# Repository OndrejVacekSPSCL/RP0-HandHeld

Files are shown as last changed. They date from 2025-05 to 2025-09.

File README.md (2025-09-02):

# RP0-HandHeld
>*This project was made for HackClub Highway*

Raspberry Pi Zero 2 gaming handheld, that runs Retro Pie...

I always wanted gaming console that has retro games in it so I made this!

RP0-HandHeld 1

RP0-HandHeld 2

## Repository Layout

The repo is structured as follows:
- PCB-related KiCad files in the `PCB/`
- KiCAD case design in `CAD/`
- Software related stuff is located in `Software/`
- For a rough BOM, see `BOM.csv`
- For my development log, see `JOURNAL.md`
- HackClub Readme is located in `README-original.md`
  
> [!CAUTION]
> The physical version of the console is not finished yet! The tutorial will be made after the completation.

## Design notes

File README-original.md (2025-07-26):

# RP0-HandHeld
Raspberry Pi Zero 2 gaming handheld, that runs Retro Pie...

I always wanted gaming console that has retro games in it so I made this!

RP0-HandHeld 1

RP0-HandHeld 2

It consists of few key parts:
- [Screen](https://github.com/OndrejVacekSPSCL/RP0-HandHeld/edit/main/README.md#screen)
- [Audio](https://github.com/OndrejVacekSPSCL/RP0-HandHeld/edit/main/README.md#audio)
- [Battery and charging](https://github.com/OndrejVacekSPSCL/RP0-HandHeld/edit/main/README.md#battery-and-charging)
- [Inputs](https://github.com/OndrejVacekSPSCL/RP0-HandHeld/edit/main/README.md#inputs)
- [PCB](https://github.com/OndrejVacekSPSCL/RP0-HandHeld/edit/main/README.md#pcb)
- [Case]()
- [Software]()

You can read about how I designed it in [JOURNAL.md](https://github.com/OndrejVacekSPSCL/RP0-HandHeld/blob/main/JOURNAL.md).

## Screen
I found this [screen](https://tinyurl.com/3287bkxc) online. It has the perfect size for my project.



## Audio
Audio is made with help of this [tutorial](https://youtu.be/3pXB90IDNoY?si=AYgq76n8aVKT-kv3).

Parts list:
- 2x [270 Ohm resistors](https://tinyurl.com/ycs5rh84)
- 2x [150 Ohm resistors](https://tinyurl.com/ycs5rh84)
- 2x [10 uf electrolitic Capacitors](https://tinyurl.com/2p6z8e5f)
- 2x [0.01 uf Polyester-Film Capacitors](https://tinyurl.com/33zae35e)
- [Speaker](https://tinyurl.com/4ueak527)
- custom PCB

This is how they should be conected:



## Battery and charging
This device is powered by [2000mAh battery](https://tinyurl.com/25jmx5w2) It uses [voltage booster](https://tinyurl.com/4jvbk29v) (3.7V on battery -> 5V for screen and RP0), [battery charge indicator](https://tinyurl.com/5596b6uh), switch and [USB-C port](https://tinyurl.com/2bktbsuc) for charging.



## Inputs
This game console will use [rubber dome switches](https://www.aliexpress.com/item/32866761020.html). Those are used in normal gamepads. They will be attached like this:



## PCB
This is the PCB:



RP0-HandHeld

## Wiring diagram
This shows, how to wire everything together:

Bez názvu

## Case
Case is made from few 3D printed pieces.

## Software
It runs RetroPie. It is needed to tweak with few files to get the buttons running. There is tutorial in the software folder...

## BOM
|Part |Quantity needed|Quantity in set|Price(USD)|Shipping(USD)|Note |Link |
|---|---|---|---|---|---|---|
|Raspberry Pi zero 2W |1 |1 |30.65 |Free |Might buy locally. That would be ~23.5 USD with shipping...|https://www.aliexpress.com/item/1005005876463565.html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 |
|Touch screen |1 |1 |31.41 |8.95 | |https://www.aliexpress.com/item/1005007372530555.html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 |
|470 Ohm resistors |2 |20 |0.87 |1.20 | |https://www.aliexpress.com/item/1005006546596146.html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 |
|270 Ohm resistors |2 |20 |0.87 |1.20 | |https://www.aliexpress.com/item/1005006546596146.html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 |
|150 Ohm resistors |2 |20 |0.87 |1.20 | |http://aliexpress.com/item/1005006546596146.html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 |
|10 uf electrolitic Capacitors |2 |30 |1.23 |Free | |https://www.aliexpress.com/item/32895970824.html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 |
|0.01 uf Polyester-Film Capacitors(103J)|2 |20 |2.50 |Free | |https://www.aliexpress.com/item/1005007139328345.html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 |
|Speaker |1 |2 |3.95 |Free | |https://tinyurl.com/22fu8ykr |
|Audio amplifier |1 |1 |1.29 |Free |Alternative to Adafruit Mono 2.5W Class D Audio Amplifier  |https://www.aliexpress.com/item/1005005926858790.html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 |
|PCB |1 |5 |2.00 |1.50 | | |
|Switches |10 |10 |1.03 |1.08 | |https://www.aliexpress.com/item/32866761020.html |
|Wires(28AWG) |1 |1 |3.00 |Free | |https://www.aliexpress.com/item/1005007009685328.html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 |
|Battery |1 |1 |13.82 |Free | |https://www.aliexpress.com/item/1005008087303778.html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 |
|PWR Switch |1 |5 |1.63 |Free | |https://www.aliexpress.com/item/32873386670.html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 |
|Voltage booster(5V) |1 |1 |0.94 |0.48 | |https://www.aliexpress.com/item/1005006342017830.html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|
|USB-C inupt with cables |1 |5 |2.33 |Free | |https://www.aliexpress.com/item/1005007469640237.html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 |
|Battery charge indicator(1S) |1 |1 |0.94 |0.65 | |https://www.aliexpress.com/item/1005006713968836.html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 |
|Total | | |114.94 | |Price with shipping | |

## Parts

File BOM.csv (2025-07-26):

Part | Quantity needed | Quantity in set | Price(USD) | Shipping(USD) | Note | Link
Raspberry Pi zero 2W | 1 | 1 | 30.65 | Free | Might buy locally. That would be ~23.5 USD with shipping... | https://www.aliexpress.com/item/1005005876463565.html?utparam-url=scene%3Asearch%7Cquery_from%3A
Touch screen | 1 | 1 | 31.41 | 8.95 |  | https://www.aliexpress.com/item/1005007372530555.html?utparam-url=scene%3Asearch%7Cquery_from%3A
470 Ohm resistors | 2 | 20 | 0.87 | 1.20 |  | https://www.aliexpress.com/item/1005006546596146.html?utparam-url=scene%3Asearch%7Cquery_from%3A
270 Ohm resistors | 2 | 20 | 0.87 | 1.20 |  | https://www.aliexpress.com/item/1005006546596146.html?utparam-url=scene%3Asearch%7Cquery_from%3A
150 Ohm resistors | 2 | 20 | 0.87 | 1.20 |  | http://aliexpress.com/item/1005006546596146.html?utparam-url=scene%3Asearch%7Cquery_from%3A
10 uf electrolitic Capacitors | 2 | 30 | 1.23 | Free |  | https://www.aliexpress.com/item/32895970824.html?utparam-url=scene%3Asearch%7Cquery_from%3A
0.01 uf Polyester-Film Capacitors(103J) | 2 | 20 | 2.50 | Free |  | https://www.aliexpress.com/item/1005007139328345.html?utparam-url=scene%3Asearch%7Cquery_from%3A
Speaker | 1 | 2 | 3.95 | Free |  | https://tinyurl.com/22fu8ykr
Audio amplifier | 1 | 1 | 1.29 | Free | Alternative to Adafruit Mono 2.5W Class D Audio Amplifier | https://www.aliexpress.com/item/1005005926858790.html?utparam-url=scene%3Asearch%7Cquery_from%3A
PCB | 1 | 5 | 2.00 | 1.50
Switches | 10 | 10 | 1.03 | 1.08 |  | https://www.aliexpress.com/item/32866761020.html
Wires(28AWG) | 1 | 1 | 3.00 | Free |  | https://www.aliexpress.com/item/1005007009685328.html?utparam-url=scene%3Asearch%7Cquery_from%3A
Battery | 1 | 1 | 13.82 | Free |  | https://www.aliexpress.com/item/1005008087303778.html?utparam-url=scene%3Asearch%7Cquery_from%3A
PWR Switch | 1 | 5 | 1.63 | Free |  | https://www.aliexpress.com/item/32873386670.html?utparam-url=scene%3Asearch%7Cquery_from%3A
Voltage booster(5V) | 1 | 1 | 0.94 | 0.48 |  | https://www.aliexpress.com/item/1005006342017830.html?utparam-url=scene%3Asearch%7Cquery_from%3A
USB-C inupt with cables | 1 | 5 | 2.33 | Free |  | https://www.aliexpress.com/item/1005007469640237.html?utparam-url=scene%3Asearch%7Cquery_from%3A
Battery charge indicator(1S) | 1 | 1 | 0.94 | 0.65 |  | https://www.aliexpress.com/item/1005006713968836.html?utparam-url=scene%3Asearch%7Cquery_from%3A
Total |  |  | 114.94 |  | Price with shipping

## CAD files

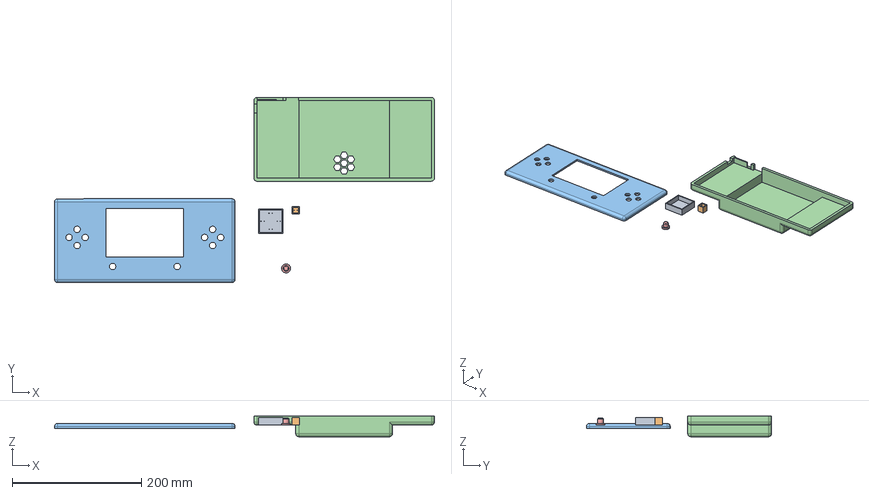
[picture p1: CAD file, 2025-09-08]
CAD/RP0 - New case.step
588.8 x 287.1 x 32.0 mm
Button holder
Top Cover
Bottom Cover
Button

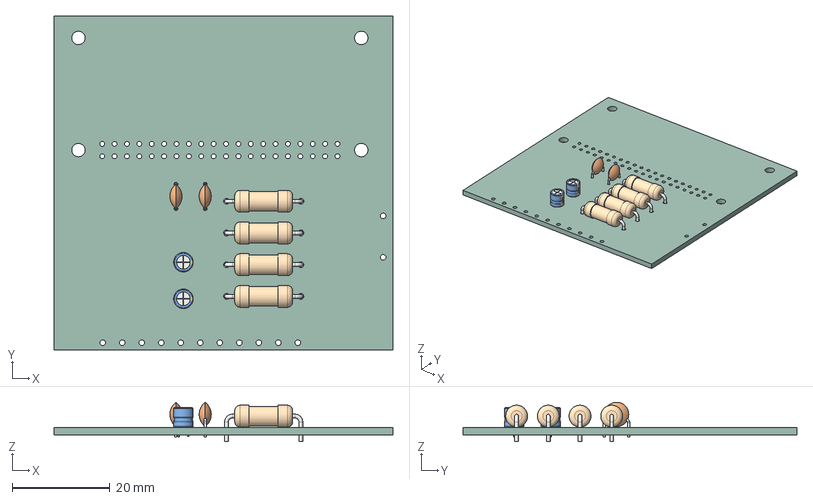
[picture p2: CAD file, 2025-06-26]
CAD/RP0-HandHeld.step
69.5 x 68.5 x 8.10 mm
C_Disc_D5.0mm_W2.5mm_P5.00mm x 2
CP_Radial_D4.0mm_P2.00mm x 2
R_Axial_DIN0414_L11.9mm_D4.5mm_P15.24mm_Horizontal x 4
RP0-HandHeld_PCB

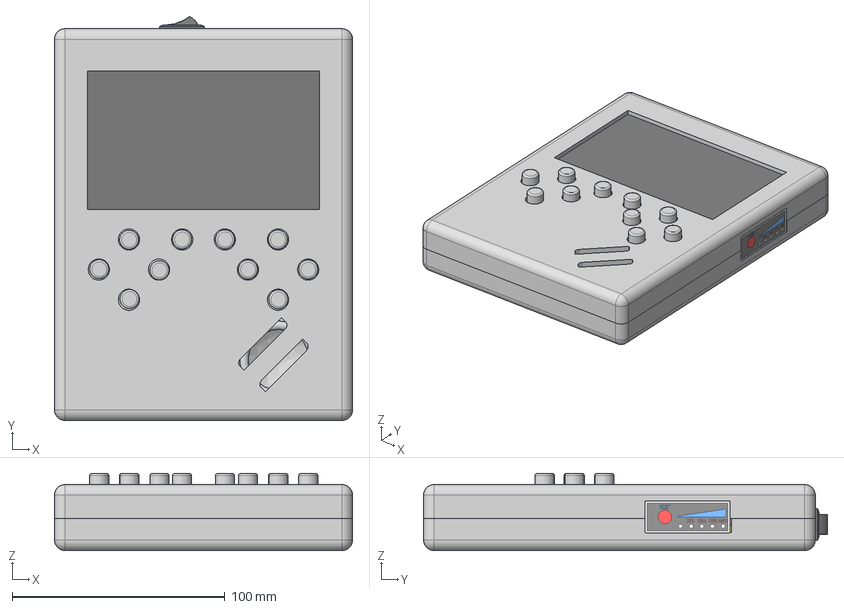
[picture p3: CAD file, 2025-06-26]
production/RP0-HandHeld.step
140.1 x 189.7 x 36.2 mm
CaseBottom
DSI x 2
12mmSpacer x 4
C_Disc_D5.0mm_W2.5mm_P5.00mm x 2
CP_Radial_D4.0mm_P2.00mm x 2
R_Axial_DIN0414_L11.9mm_D4.5mm_P15.24mm_Horizontal x 4
RP0-HandHeld_PCB
PCB, Raspberry Pi Zero 2 W
RP3A0-AU 2105 201221C, Raspberry Pi Zero 2 W
MicroUSB Port, Raspberry Pi Zero 2 W x 2
SD Card Slot, Raspberry Pi Zero 2 W
Wireless Module Cover, Raspberry Pi Zero 2 W
Crystal Resonator, Raspberry Pi Zero 2 W
LED, Raspberry Pi Zero 2 W
Diode, Schottky, Raspberry Pi Zero 2 W
54548-2271, 22 Pin FPC Connector, Raspberry Pi Zero 2 W
Mini HDMI Receptacle Port, Raspberry Pi Zero 2 W
PAM2306AYPKE, Switching Voltage Regulators Dual PWM Step-Down 40uA 1A 1.5MHz, Raspberry Pi Zero 2 W
RT9081A-1BGQZA, Fixed LDO Voltage Regulator, 0.8V-5.5Vin, 140mV drop, 1.25Vout, 0.5Aout, Raspberry Pi Zero 2 W_default
RT8088AWSC, IC Reg Buck Prog 3A Sync 15WLCSP, Raspberry Pi Zero 2 W_d efault
SMD Inductor, Configurable, Raspberry Pi Zero 2 W_L1
SMD Inductor, Configurable, Raspberry Pi Zero 2 W_L2
SMD Capacitor, Configurable, Raspberry Pi Zero 2 W_C1 x 3
SMD Capacitor, Configurable, Raspberry Pi Zero 2 W_C3 x 7
SMD Capacitor, Configurable, Raspberry Pi Zero 2 W_C2 x 31
SMD Capacitor, Configurable, Raspberry Pi Zero 2 W_C10 x 15
SMD Resistor, Configurable, Raspberry Pi Zero 2 W_R1 x 20
SMD Resistor, Configurable, Raspberry Pi Zero 2 W_R12
Altoparlante
Buttons
panel_on-off_spdt
TYPE-C-14-vertical_H-10mm_µ¼³öAltium¶ÔÆë Ôµã
Battery Indicator 40X15X2.5
Kapton Tape
Battery Cell
Board Part 1
PCB
Positive
Negative
Board Part 2
Board
MAX98306ETD+T
10µF x 10
OUTR x 2

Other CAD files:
CAD/RP0 - New case.obj
CAD/RP0 - New case.stl
production/RP0 - New case.obj
production/RP0 - New case.stl

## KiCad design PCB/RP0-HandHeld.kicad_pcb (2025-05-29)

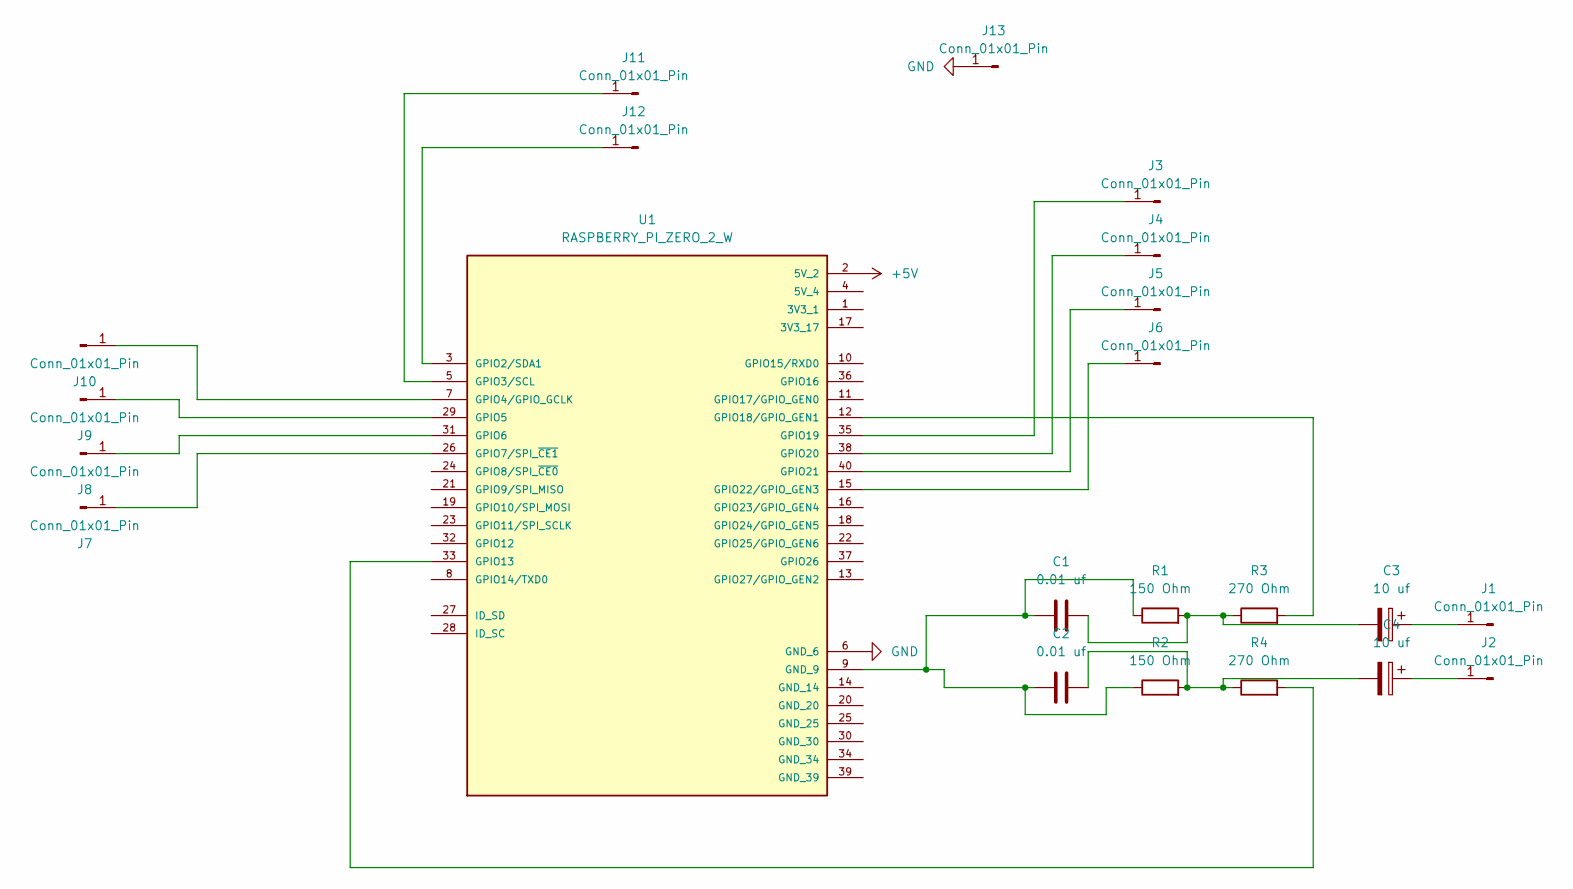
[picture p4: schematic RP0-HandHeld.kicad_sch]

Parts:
C1, C2: 0.01 uf; C_Disc_D5.0mm_W2.5mm_P5.00mm
C3, C4: 10 uf; CP_Radial_D4.0mm_P2.00mm
J1, J2, J3, J4, J5, J6, J7, J8, J9, J10, J11, J12, J13: Conn_01x01_Pin; SolderWire-0.5sqmm_1x01_D0.9mm_OD2.3mm
R1, R2: 150 Ohm; R_Axial_DIN0414_L11.9mm_D4.5mm_P15.24mm_Horizontal
R3, R4: 270 Ohm; R_Axial_DIN0414_L11.9mm_D4.5mm_P15.24mm_Horizontal
U1: RASPBERRY_PI_ZERO_2_W; MODULE_RASPBERRY_PI_ZERO_2_W; PARTREV April 2024

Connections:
+5V: U1.2 (5V_2)
GND: J13.1, U1.6 (GND_6)
unnamed: C1.2, C3.2, R1.2, R3.1
unnamed: C2.2, C4.2, R2.2, R4.1
unnamed: C3.1, J1.1
unnamed: C4.1, J2.1
unnamed: J3.1, U1.35 (GPIO19)
unnamed: J4.1, U1.38 (GPIO20)
unnamed: J5.1, U1.40 (GPIO21)
unnamed: J6.1, U1.15 (GPIO22/GPIO_GEN3)
unnamed: J7.1, U1.26 (GPIO7/SPI_~CE1)
unnamed: J8.1, U1.31 (GPIO6)
unnamed: J9.1, U1.29 (GPIO5)
unnamed: J10.1, U1.7 (GPIO4/GPIO_GCLK)
unnamed: J11.1, U1.5 (GPIO3/SCL)
unnamed: J12.1, U1.3 (GPIO2/SDA1)
unnamed: C1.1, C2.1, R1.1, R2.1, U1.9 (GND_9)
unnamed: R4.2, U1.33 (GPIO13)
unnamed: R3.2, U1.12 (GPIO18/GPIO_GEN1)

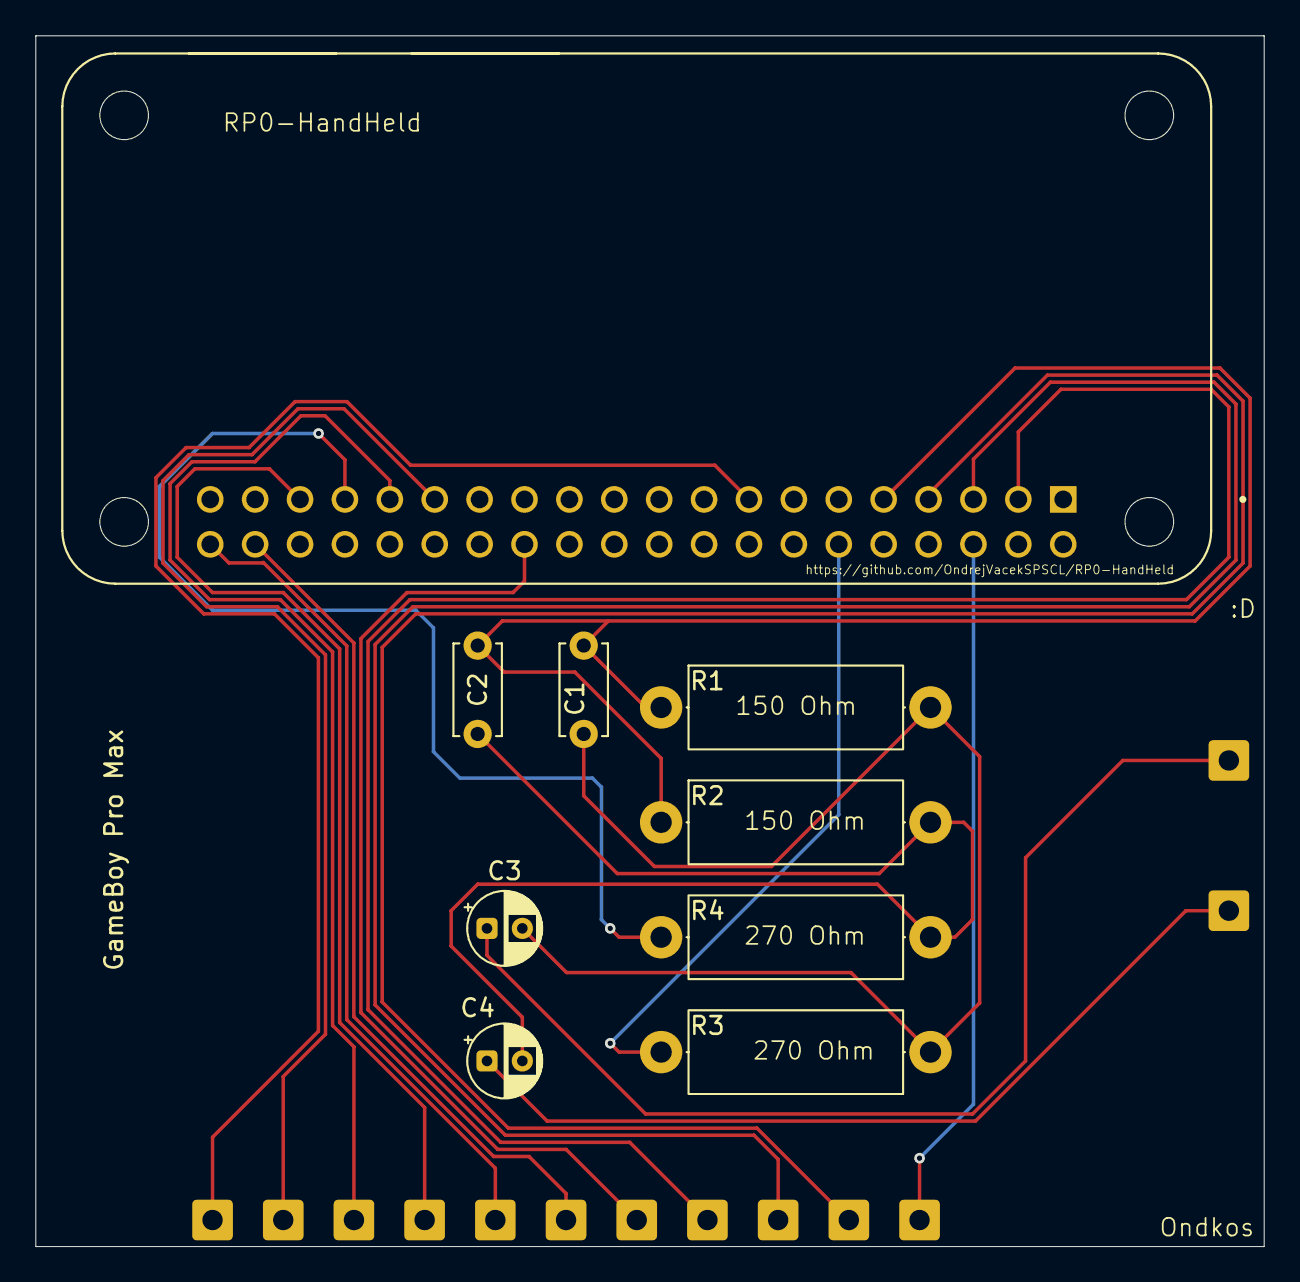
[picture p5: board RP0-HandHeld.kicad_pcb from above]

Board: 2 copper layers, 69.5 x 68.5 mm, 22 parts (0 on the bottom side), 18 nets.

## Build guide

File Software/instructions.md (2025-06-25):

## Installing RetroPie
Install [RaspberryPI](https://www.raspberrypi.com/software/) imager to your host OS.

Than chose device (Raspberri Pi zero 2 W). Than chose OS -> Emulation and games OS -> RetroPie -> RetroPie 4.8 (RPI 2/3/Zero 2 W).

Insert your micrioSD card (chose minimum 32GB card) and select it.

It should look something like this:



When it finishes unplug it, put it in your RaspberryPI and power it on

## Input
First We need to install [GPIOnext](https://github.com/mholgatem/GPIOnext)
in terminal type:
- cd ~
- git clone https://github.com/mholgatem/GPIOnext.git
- bash GPIOnext/install.sh

If it asks you if you want to run configuration manager type n (that means no :D)

Than type:  
  sudo python3 /home/pi/GPIOnext/config_manager.py --pins 3,5,7,15,26,29,31,35,38,40

Than chose: Joypad 1
Our console has 1 dpad so chose that. 
We also have:
- start button
- select button
- A
- B
- X
- Y

It will as you to press the buttons. Do it. It will look something like this:



When you finish configuration chose EXIT.
Than run:
- gpionext set pins 3,5,7,15,26,29,31,35,38,40
- gpionext start
- sudo reboot now

When it reboots it shoud show that nothing has been configured yet, but it should detect our controller. Hold one of the buttons ant it shoud start the configuration process. To skip oveer the buttons that we don't have just press and hold one button (for example select).

## Audio
run "sudo nano /boot/config.txt" and add the text that is saved in config.txt and save

than "sudo reboot"

after it restarts run "sudo raspi-config"

go to "Advanced Options" than "Audio" and "Force 3.5mm (headphone) jack"

than run "alsamixer" and turn the audio up

to test it out run "aplay /usr/share/sounds/alsa/Front_Center.wav"

## Installing games
To install your favourite games to our console you'll need usb stick (it is recomended to use one with activity light). Plug it into your computer and create folder named retropie



Than connect it to your RPI and wait for a few minutes (or whan the activity light stops blinking). Than put it back into your PC. When you open the retropi folder you shoul see something like this: 



When you open the roms folder you should find this: 



Than just put your games into the coresponding folders...

Than connect it to your RPI and it wil transfer the games files. Wait untill the activity light stops blinking.

Than go into the RetroPie MAIN MENU  -> QUIT -> RESTART EMULATIONSTATION

After that you should see your games in the RetroPie menu :)

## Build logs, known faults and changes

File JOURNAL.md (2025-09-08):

---
title: "RP0 Handheld"
author: "Ondkos"
description: "Raspberry Pi Zero 2 gaming handheld console that runs on RetroPie!"
created_at: "2025-05-26"
---
### **Total time spent: 20.6hr**

## 27th May: Start of the project
Yesterday i started thinking about this project. I was searching the web for suitable RP and settled on RP Zero 2W. It should have enought power to run some games on RetroPie. I chose the zero 2W, becouse it is really small. That is usefull because i am making handheld.

Today I started searching the web for other parts.

I will need:

- Screen
    
- Some way to get audio
    
- Inputs
    
- Battery and charging module.

 ### Screen
 First i started looking for display. I wanted somethig between 4" and 6". I was thinking about [this one](https://www.amazon.de/dp/B085TC5YMR?ref=myi_title_dp&th=1) or [this one](https://tinyurl.com/ev4p9sd7), but they were to small. Than I found this [5" display](https://tinyurl.com/3287bkxc) (the touch variant for easier manipulation). Downside on this one is that it uses HDMI and not the pins on the RP.



### Audio
 Than I started to think about the audio. There are three ways I can get it from RP0.
 
1. Buy cheap USB dongle
    
2. Buy [premade DAC HAT for RP](https://shop.pimoroni.com/products/audio-amp-shim-3w-mono-amp?variant=32341591064659)
    
3. Make my own audio output system with help of [tutorial](https://youtu.be/3pXB90IDNoY?si=AYgq76n8aVKT-kv3)
    
I was thinkig about the second option, but than I said to myself that It would be to easy :D. I will need:

- 2x [270 Ohm resistors](https://tinyurl.com/ycs5rh84)
- 2x [150 Ohm resistors](https://tinyurl.com/ycs5rh84)
- 2x [10 uf electrolitic Capacitors](https://tinyurl.com/2p6z8e5f)
- 2x [0.01 uf Polyester-Film Capacitors](https://tinyurl.com/33zae35e)
- [Speaker](https://tinyurl.com/4ueak527)
- custom PCB

Here is schematic of how it should be connected



### Inputs
I looked into how game controllers work. I found this [reddit post](https://www.reddit.com/r/AskElectronics/comments/8lt9gv/what_kind_of_pushbuttons_do_game_controllers_use/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) and through the comments I found [those switches](https://www.aliexpress.com/item/32866761020.html). They are rubber dome switches, you could find something similar in membrane keyboards. Thay will be conected by [wire](https://tinyurl.com/4vmrkypu). I wanted to make PCB for them, but that would be harder to attach it to the case...



### Battery and charging module
With the help of this [video](https://youtu.be/wPQf_Pz0APA?si=iIAJfkxdQpS1blh7) I learned how to charge the RP0 from battery. ~~I found [cheap voltage booster](https://tinyurl.com/429w3p3t), because the one he uses in the video is almost 15x more expensive.~~ I also found this [battery](https://tinyurl.com/25jmx5w2). Because I don't want to have the RP0 take the power all the time I also found those [switches](https://tinyurl.com/34hr93tu).

**Time spent: 5hr**

## 28th May: PCB and batteries

### Battery and charging module 
I found out that the vlotage booster i found yesterday doesn't suport charging... So I found [new one](https://tinyurl.com/4jvbk29v) that does. I wil also need some [USB-C inupt with cables](https://tinyurl.com/2bktbsuc). Because i also want to know how charged the battery is i will need [battery charge indicator](https://tinyurl.com/5596b6uh).

This is how it will look like:



### PCB
I started working on the PCB for my project. I found this [footprint](https://www.snapeda.com/parts/RASPBERRY%20PI%20ZERO%202%20W/Raspberry%20Pi/view-part/) of RP0 that I'll use.

I started working on the schematic, and created this:



I had lots of problems with finding the right footprints for the resistors and capacitors...

After some time I finished the PCB



### Audio
I found parts (resistors, capacitors, etc.) and added the links to the list above.

**Time spent: 5.5hr**

## 29th May: Remaking the PCB

### PCB
Today I relised the pcb is to big, so i started remaking it... I reduced it a lot.

Height: 97mm -> 69mm

Width: 88mm -> 70mm

Here is the new version of the pcb:



### Case
I also started working on the case.
Here is drawing of the layout of the case:



I realised that It will be huge even after the PCB edit, so I'm thinking about renaming it "GameBoy Pro Max" :D

With help of the scatch above I managed to create model of the bottom case.



And than I started to work on the top part. It is still without button holes, but that will wait...



**Time spent: 3.5hr**

## 2nd June: Small Case edit
Today, I spent some more time on the case. I  created holes for the buttons. They are 10mm wide, they are 10mm apart as you can see on the second image...





I din't have much time today, so I hope I will make more progress tomorow.

**Time spent: 0.4hr**

## 3rd June: Finishing case and software 
### Case
I created small part that will hold buttons. It will be hot glued together...



This is how it will work:



I also created buttons
- Base radius: 12 mm
- Base height: 2 mm
- Radius: 9 mm
- Height: 10mm



### Software
I also started working on software. I crearted [instructions](https://github.com/OndrejVacekSPSCL/RP0-HandHeld/blob/main/Software/instructions.md) on how to change files to have working sound. It is located in Software folder...

I also foud this [video](https://www.youtube.com/watch?v=BV_nVu8Be7M) that will help me to use my buttons as inputs.

I started asigning the buttons to the GPIO pins

Snímek obrazovky 2025-06-03 215644



**Time spent: 1.5hr**

## 25th June: Audio fix, BOM and software
I havent had much time recently, but I'm back. In a few days, I will have another 14 days of not working on any projects. Hope I finish this before that...
### Audio
Today, with help of this [video](https://www.youtube.com/watch?v=KWY_wI-7vEM&t=318s), I found out that I will need [audio amplifier](https://tinyurl.com/mddsej95) similar to [this one](https://www.adafruit.com/product/2130). To connect it to the amplifier I will need [470 Ohm resistors]().

### BOM
Created BOM. It is located in the root of this repo.

### Software
I created [instructions](https://github.com/OndrejVacekSPSCL/RP0-HandHeld/blob/main/Software/instructions.md) for Installing and setting up GPIOnext, installing RetroPie and installing games.

**Time spent: 2hr**

## 26th June: ReadMe
I Started making the requested readme for the submit. I also worked on the render for the readme:



Created the wiering diagram for the ReadMe:

Bez názvu

and added BOM to readme.

**Time spent: 2.7hr**

>From now I journal for myself, not for HackClub

## 5th September: Issues
All the parts arived few days ago and ia started working on the physical project. I realised the case design wont work, becouse of these cables:



That means I will need to remake it. Make it bigger, or change the design...

## 8th September: New case
I created new case design. It can be found in  [CAD/](https://github.com/OndrejVacekSPSCL/RP0-HandHeld/tree/main/CAD)



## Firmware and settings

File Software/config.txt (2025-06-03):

#EnablingPWM audio through device tree
dtoverlay=pwm-2chan,pin=18,func=2,pin2=13,func2=4

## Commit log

2025-05-28 Created PCB folder
    [RP0-HandHeld.kicad_pcb, RP0-HandHeld.kicad_sch]
2025-05-28 Created PCB schematic
    [RP0-HandHeld.kicad_sch]
2025-05-28 Started working on the pcb
    [RP0-HandHeld.kicad_pcb, RP0-HandHeld.kicad_sch]
2025-05-28 Finished PCB
    [RP0-HandHeld.kicad_pcb]
2025-05-28 Added gitignore for KiCad
2025-05-29 Redesigned the PCB
    [RP0-HandHeld.kicad_pcb]
2025-05-29 Edited silkscreen PCB
    [RP0-HandHeld.kicad_pcb]
2025-06-03 added software folder
    [config.txt]
2025-06-26 production files added
    [RP0-HandHeld.step]
2025-09-08 New case
    [RP0 - New case.obj, RP0 - New case.step, RP0 - New case.stl]
